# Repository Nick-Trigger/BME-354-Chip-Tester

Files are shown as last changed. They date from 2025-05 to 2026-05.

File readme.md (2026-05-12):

# BME 354 Chip Tester

A custom PCB designed to test analog ICs — specifically the ADC623 and INA126 instrumentation amplifiers — as part of a BME 354 course project.

## Overview

The board provides:

- A sine wave generator signal source
- A regulated voltage supply
- LED indicators for pass/fail output comparison
- Switch-controlled power and signal routing
- Test points for oscilloscope / multimeter probing

## Project Files

| Folder / File | Description |
| --- | --- |
| [KiCad_milling_machine/](KiCad_milling_machine/) | KiCad schematic and PCB layout files (milling-machine spec) |
| [KiCad_milling_machine/Custom Libraries/](KiCad_milling_machine/Custom%20Libraries/) | Custom KiCad symbols and footprints for non-standard parts |
| [Documentation/](Documentation/) | Photos from build and testing stages |
| [Documentation.md](Documentation.md) | Full design log with dated entries and schematic notes |

## Key Schematics

- [ChipTester_354.kicad_sch](KiCad_milling_machine/ChipTester_354.kicad_sch) — top-level schematic
- [AD_INA.kicad_sch](KiCad_milling_machine/AD_INA.kicad_sch) — ADC623 / INA126 test circuit
- [wave_generator.kicad_sch](KiCad_milling_machine/wave_generator.kicad_sch) — sine wave generator sub-circuit
- [pwrsup.kicad_sch](KiCad_milling_machine/pwrsup.kicad_sch) — voltage regulator sub-circuit
- [mcp_if.kicad_sch](KiCad_milling_machine/mcp_if.kicad_sch) — MCP interface sub-circuit

## Design Log

See [Documentation.md](Documentation.md) for a full chronological record of design decisions, breadboard testing, PCB layout, milling, soldering, and troubleshooting.

## Components

Non-standard parts sourced from DigiKey. Custom footprints included in [KiCad_milling_machine/Custom Libraries/](KiCad_milling_machine/Custom%20Libraries/) for:

- `100DP1T2B4M6QE` — DPDT slide switch
- `100SP3T2B4M6RE` — SP3T slide switch
- `7101MD9AQE` — rotary switch
- `BH9VPC` — 9V battery holder
- `PRS12R_4025K_103B1` — potentiometer

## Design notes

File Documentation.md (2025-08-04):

## Circuit Design 
May 19th 2025

* Created beginning of circuit design for for ADC623 INA126 testing circuit 
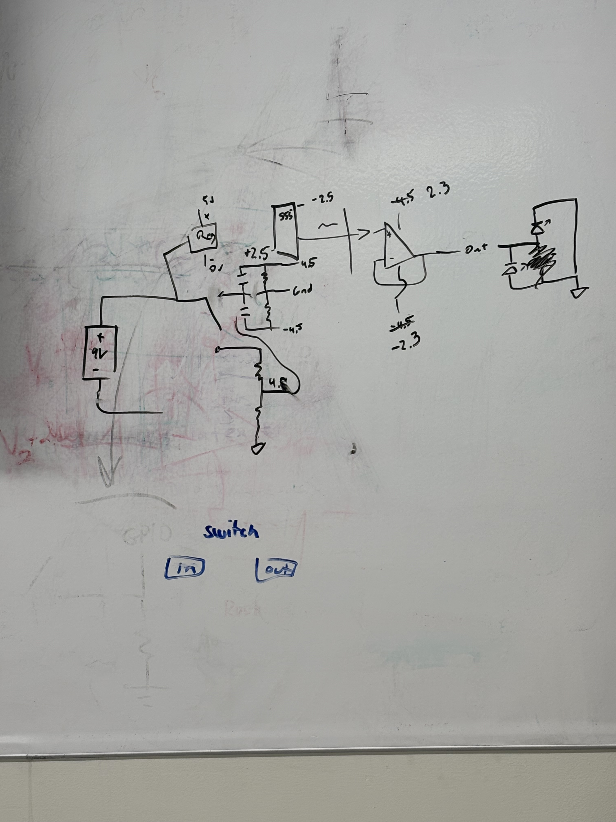
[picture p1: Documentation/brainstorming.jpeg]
Circuit Brainstorming

* Started with Kicad circuit creation

May 20th 2025

* Built and Tested Voltage Regulator Circuit (working)
* Built and Tested Sine Wave Generator Circuit (working)
    * Decided against using 555 timer for sine wave oscillating signal 
    * Both circuits were built on an open breadboard to start with to allow us to troubleshoot easily 
    * Decided on Potentionmeter Min Resistance as 10kOhm 
 
Breadboard Testing Circuits

May 28th 2025

* Ordered components from DigiKey ([List](https://www.digikey.com/en/mylists/list/94XYNUR698))

May 29th 2025 

* Started PCB layout, found footprints for non-standard parts.

June 2nd-3rd 2025

* Reannotated schematic and pcb.
* Finished pcb layout.

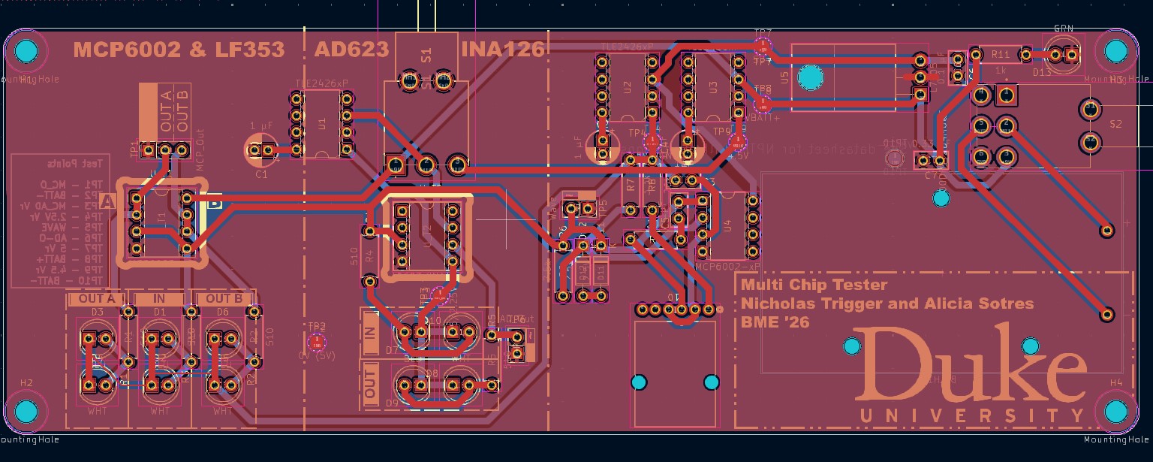
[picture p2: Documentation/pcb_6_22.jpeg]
Finished PCB schematic 6/2/25


June 4th 2025 

* Duplicated board file to modify for milling machine specification.

June 10th 2025 

* Edited PCB schematic for remilling. Fixed clearance issues with tracks. 
* Changed through-hole diameters to allow for rivets to be placed in difficult to solder locations (chip and pin sockets)

June 25th 2025

* Received milled board, tested board for issues before soldering. 
* Soldered main components, need more blue and white LEDS

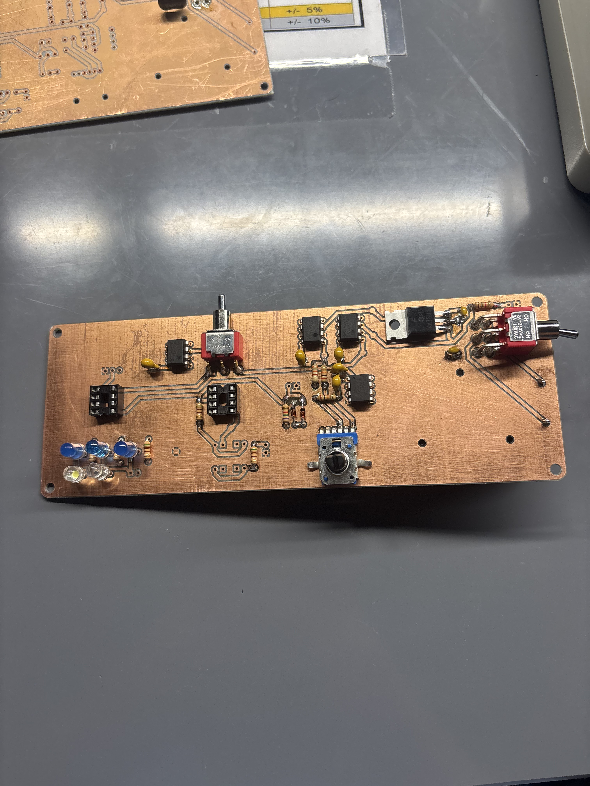
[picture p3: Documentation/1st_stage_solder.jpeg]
Incomplete PCB 6/2/25


July 29th 2025
* Rebuilt circuit on breadboard to troubleshoot known issues identified on first milled PCB
    * Issues included LED ground, necessary chip connections and switch issues. 
    * Removed 2nd switch to simplify circuit logic. 

August 4th 2025 

* Updated schematic to ground LEDs to board GND to allow for simultaneous blinking. 

## PCB & Schematic Notes
* (7/24/2025) The voltage provided by the battery has four different net class names (two before and two after the power switch). This is to distinguish between the nets so that KiCad does not draw a connection between these two signals, bridging across the switch -- making it useless.

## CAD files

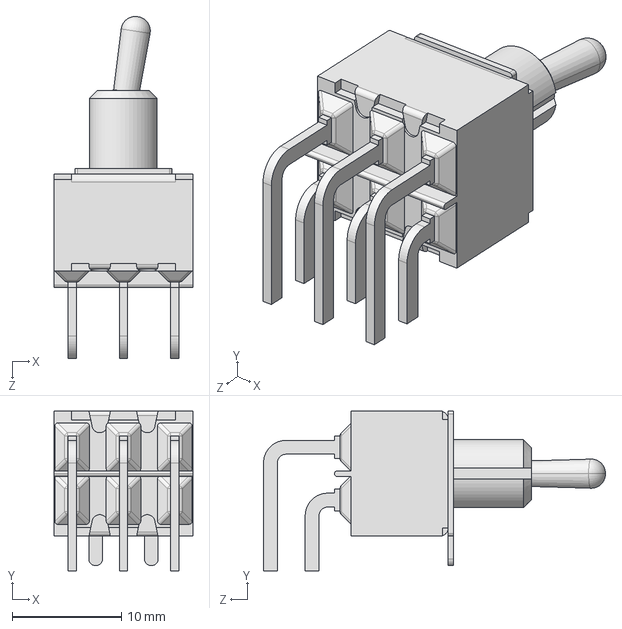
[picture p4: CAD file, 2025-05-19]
KiCad_milling_machine/Custom Libraries/100DP1T2B4M6QE/100DP1T2B4M6QE.step
12.7 x 14.6 x 31.3 mm

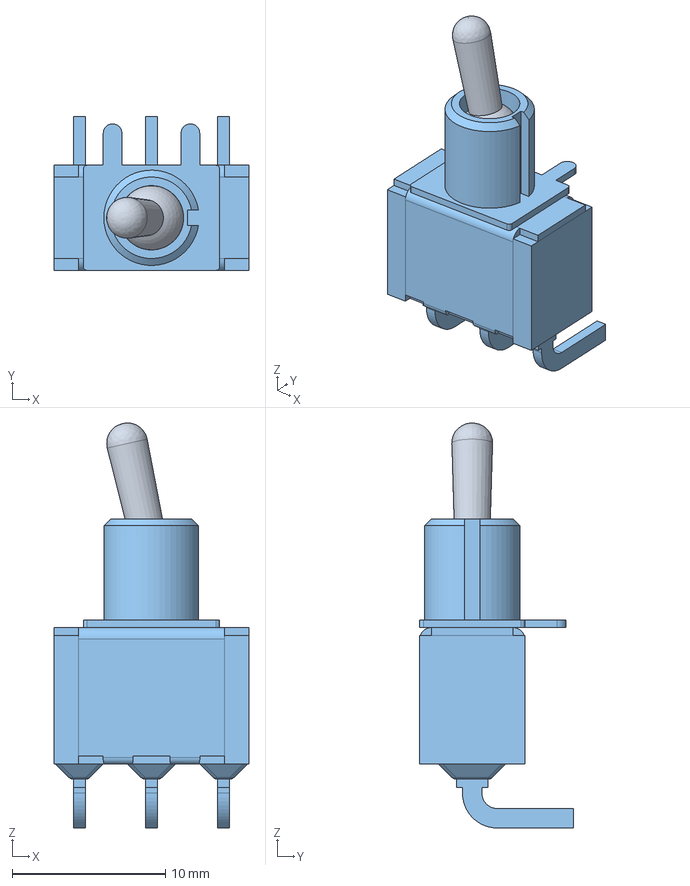
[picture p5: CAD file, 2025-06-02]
KiCad_milling_machine/Custom Libraries/100SP3T2B4M6RE/100SPxT2B4M6xE.stp
12.7 x 10.0 x 26.4 mm

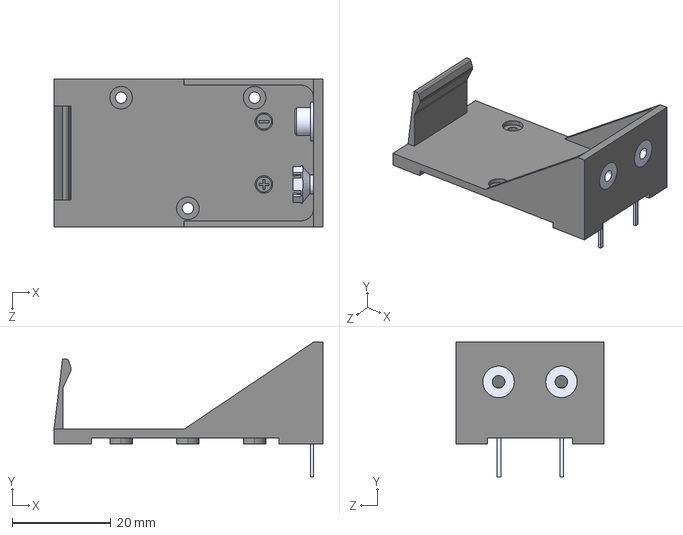
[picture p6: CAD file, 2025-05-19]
KiCad_milling_machine/Custom Libraries/BH9VPC/BH9VPC.step
54.4 x 27.2 x 30.0 mm

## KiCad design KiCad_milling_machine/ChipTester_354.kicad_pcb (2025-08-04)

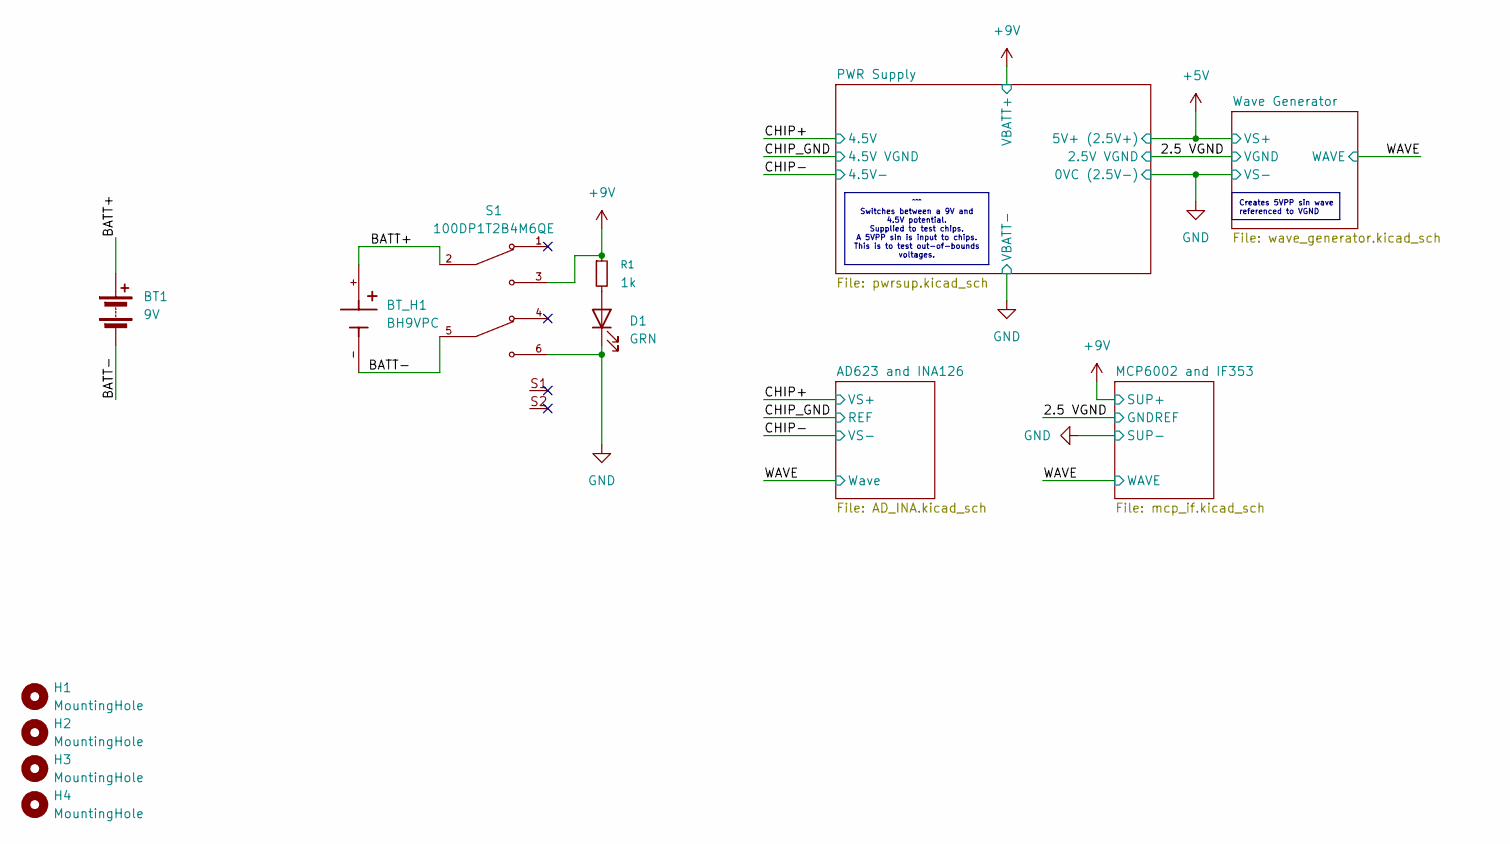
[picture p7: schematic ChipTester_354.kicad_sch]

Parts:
BT1: 9V
BT_H1: BH9VPC; BAT_BH9VPC; PARTREV F
D1: GRN; LED_D5.0mm
H1, H2, H3, H4: MountingHole; MountingHole_3.2mm_M3
R1: 1k; R_Axial_DIN0207_L6.3mm_D2.5mm_P7.62mm_Horizontal
S1: 100DP1T2B4M6QE; SW_100DP1T2B4M6QE; PARTREV G

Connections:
+9V: R1.1, S1.3; also elsewhere on the board
/BATT+: BT1.1 (+), BT_H1.+, S1.2
/BATT-: BT1.2 (-), BT_H1.-, S1.5
GND: D1.1 (K), S1.6; also elsewhere on the board
unnamed: D1.2 (A), R1.2

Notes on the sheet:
Creates 5VPP sin wave referenced to VGND
^^^ Switches between a 9V and 4.5V potential. Supplied to test chips. A 5VPP sin is input to chips. This is to test out-of-bounds voltages.

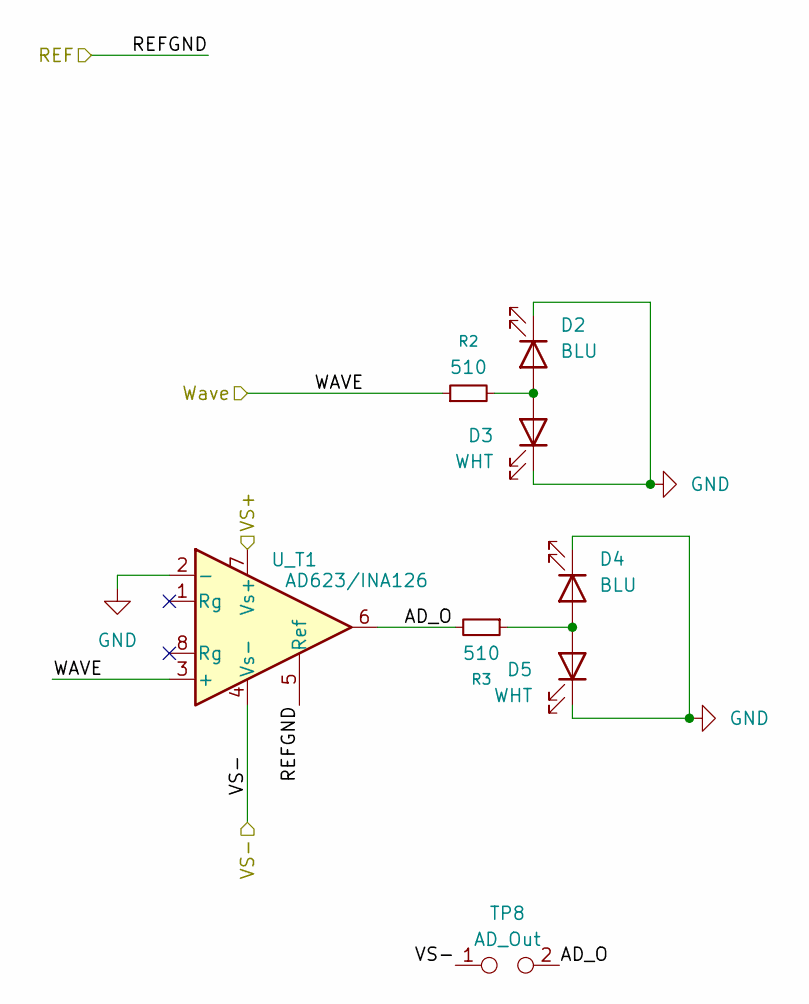
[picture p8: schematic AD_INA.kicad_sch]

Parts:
D2, D4: BLU; LED_D5.0mm
D3, D5: WHT; LED_D5.0mm
R2, R3: 510; R_Axial_DIN0207_L6.3mm_D2.5mm_P7.62mm_Horizontal
TP8: AD_Out; PinSocket_1x02_P2.54mm_Vertical
U_T1: AD623/INA126; DIP-8_W7.62mm_Socket

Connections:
+9V: U_T1.7 (Vs+); also elsewhere on the board
/AD623 and INA126/AD_O: R3.2, TP8.2, U_T1.6
/CHIP_GND: U_T1.5 (Ref); also elsewhere on the board
/WAVE: R2.1, U_T1.3 (+); also elsewhere on the board
GND: D2.1 (K), D3.1 (K), D4.1 (K), D5.1 (K), TP8.1, U_T1.2 (-), U_T1.4 (Vs-); also elsewhere on the board
unnamed: D2.2 (A), D3.2 (A), R2.2
unnamed: D4.2 (A), D5.2 (A), R3.1

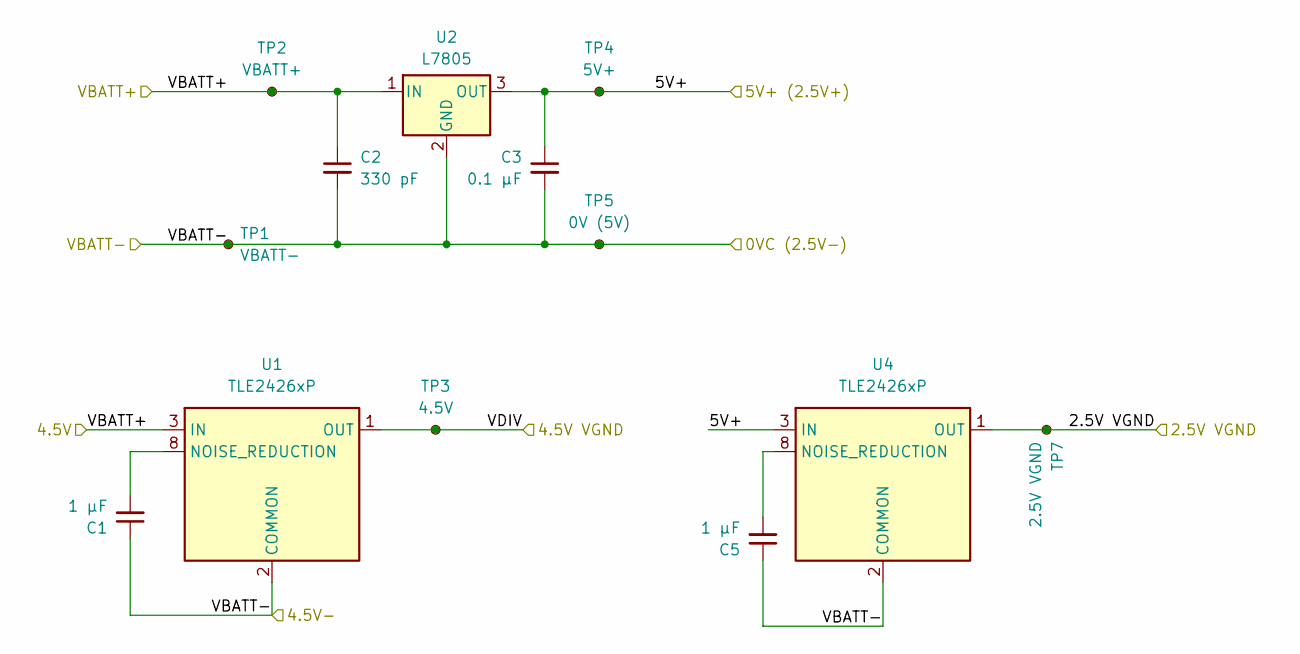
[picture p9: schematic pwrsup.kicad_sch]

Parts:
C1, C5: 1 µF; CP_Radial_D5.0mm_P2.00mm
C2: 330 pF; C_Disc_D5.0mm_W2.5mm_P2.50mm
C3: 0.1 µF; C_Disc_D5.0mm_W2.5mm_P2.50mm
TP1: VBATT-; TestPoint_Pad_D2.0mm
TP2: VBATT+; TestPoint_Pad_D2.0mm
TP3: 4.5V; TestPoint_Pad_D2.0mm
TP4: 5V+; TestPoint_Pad_D2.0mm
TP5: 0V (5V); TestPoint_Pad_D2.0mm
TP7: 2.5V VGND; TestPoint_Pad_D2.0mm
U1, U4: TLE2426xP; DIP-8_W7.62mm
U2: L7805; TO-220-3_Horizontal_TabDown

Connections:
+5V: C3.1, TP4.1, U2.3 (OUT), U4.3 (IN); also elsewhere on the board
+9V: C2.1, TP2.1, U1.3 (IN), U2.1 (IN); also elsewhere on the board
/2.5 VGND: TP7.1, U4.1 (OUT); also elsewhere on the board
/CHIP_GND: TP3.1, U1.1 (OUT); also elsewhere on the board
GND: C1.1, C2.2, C3.2, C5.1, TP1.1, TP5.1, U1.2 (COMMON), U2.2 (GND), U4.2 (COMMON); also elsewhere on the board
unnamed: C1.2, U1.8 (NOISE_REDUCTION)
unnamed: C5.2, U4.8 (NOISE_REDUCTION)

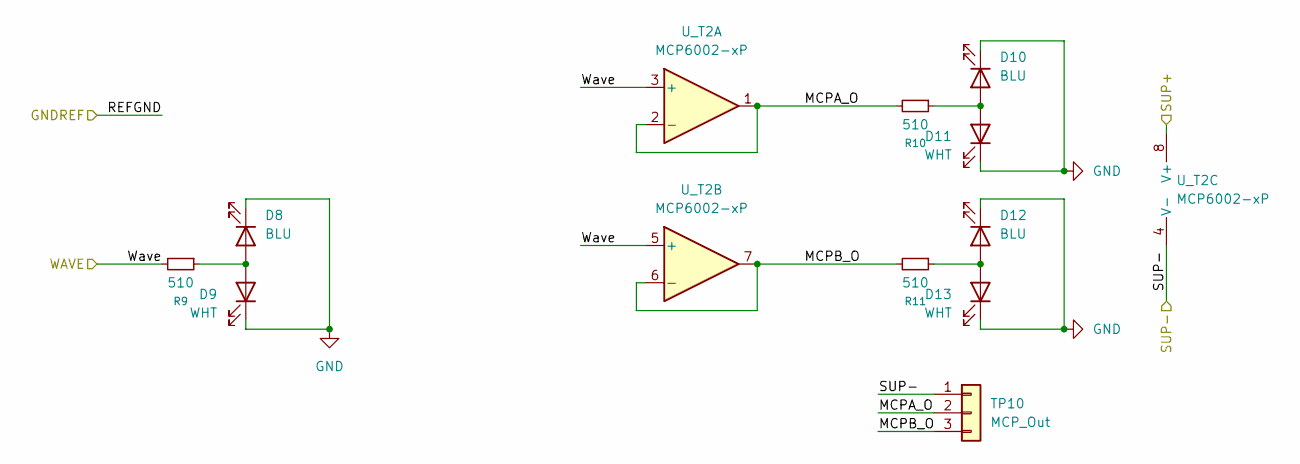
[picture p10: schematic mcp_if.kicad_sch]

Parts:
D8, D10, D12: BLU; LED_D5.0mm
D9, D11, D13: WHT; LED_D5.0mm
R9, R10, R11: 510; R_Axial_DIN0207_L6.3mm_D2.5mm_P7.62mm_Horizontal
TP10: MCP_Out; PinSocket_1x03_P2.54mm_Vertical
U_T2: MCP6002-xP; DIP-8_W7.62mm_Socket

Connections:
+9V: U_T2.8 (V+); also elsewhere on the board
/MCP6002 and IF353/MCPA_O: R10.2, TP10.2, U_T2.1, U_T2.2 (-)
/MCP6002 and IF353/MCPB_O: R11.2, TP10.3, U_T2.6 (-), U_T2.7
/WAVE: R9.2, U_T2.3 (+), U_T2.5 (+); also elsewhere on the board
GND: D8.1 (K), D9.1 (K), D10.1 (K), D11.1 (K), D12.1 (K), D13.1 (K), TP10.1, U_T2.4 (V-); also elsewhere on the board
unnamed: D8.2 (A), D9.2 (A), R9.1
unnamed: D10.2 (A), D11.2 (A), R10.1
unnamed: D12.2 (A), D13.2 (A), R11.1

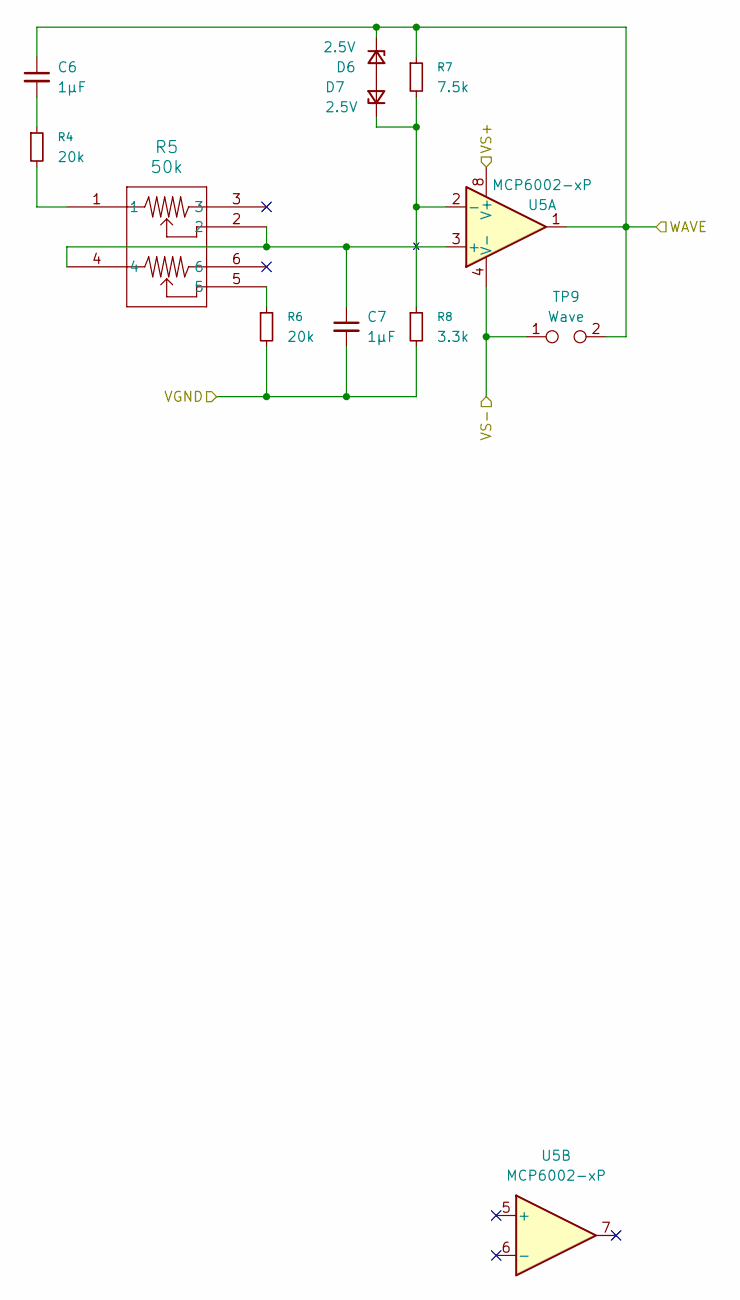
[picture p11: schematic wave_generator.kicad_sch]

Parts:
C6, C7: 1µF; C_Disc_D5.0mm_W2.5mm_P2.50mm
D6, D7: 2.5V; D_DO-35_SOD27_P7.62mm_Horizontal
R4, R6: 20k; R_Axial_DIN0207_L6.3mm_D2.5mm_P7.62mm_Horizontal
R5: 50k; PRS12R-4_BRN
R7: 7.5k; R_Axial_DIN0207_L6.3mm_D2.5mm_P7.62mm_Horizontal
R8: 3.3k; R_Axial_DIN0207_L6.3mm_D2.5mm_P7.62mm_Horizontal
TP9: Wave; PinSocket_1x02_P2.54mm_Vertical
U5: MCP6002-xP; DIP-8_W7.62mm

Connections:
+5V: U5.8 (V+); also elsewhere on the board
/2.5 VGND: C7.2, R6.2, R8.2; also elsewhere on the board
/WAVE: C6.1, D6.1 (K), R7.1, TP9.2, U5.1; also elsewhere on the board
GND: TP9.1, U5.4 (V-); also elsewhere on the board
unnamed: C6.2, R4.1
unnamed: D6.2 (A), D7.2 (A)
unnamed: D7.1 (K), R7.2, R8.1, U5.2 (-)
unnamed: R4.2, R5.1
unnamed: R5.5, R6.1
unnamed: C7.1, R5.2, R5.4, U5.3 (+)

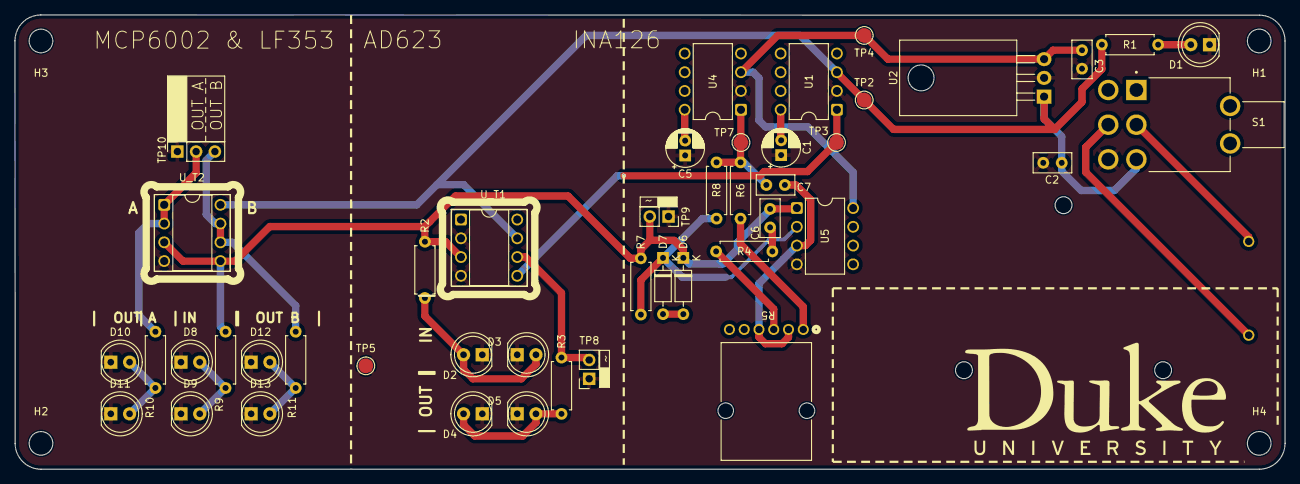
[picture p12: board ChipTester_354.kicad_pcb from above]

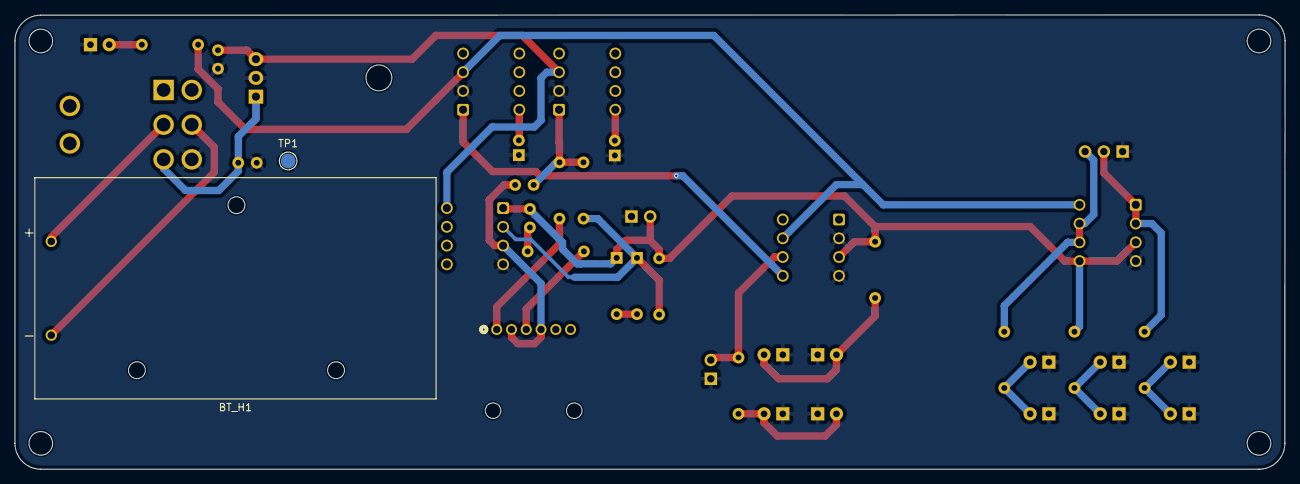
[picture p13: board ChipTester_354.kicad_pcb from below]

Board: 2 copper layers, 172.0 x 61.5 mm, 51 parts (2 on the bottom side), 25 nets.

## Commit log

2025-05-19 Added KiCad Docs and started working
    [100DP1T2B4M6QE.step, BH9VPC.step, ChipTester_354.kicad_pcb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]
2025-05-20 Finish power supply, make waveform generator.
    [AD_INA.kicad_sch, ChipTester_354.kicad_sch, pwrsup.kicad_sch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]
2025-05-21 changed resistance on schematic for minimum reisstance of 20kOhm
    [wave_generator.kicad_sch]
2025-05-28 changed resistor values after testing
    [wave_generator.kicad_sch]
2025-05-28 Change to TI rail splitter.
    [pwrsup.kicad_sch, wave_generator.kicad_sch]
2025-05-28 Swapped mcp6002 rail splitter for TI TLE2426xP
    [pwrsup.kicad_sch, wave_generator.kicad_sch]
2025-05-28 started edited pcb layout
    [ChipTester_354.kicad_pcb, ChipTester_354.kicad_sch, pwrsup.kicad_sch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]
2025-05-28 ADD AC623 and INA126 Test Circuitry
    [AD_INA.kicad_sch, ChipTester_354.kicad_sch]
2025-05-28 added footprints to schematic
    [AD_INA.kicad_sch, ChipTester_354.kicad_pcb, pwrsup.kicad_sch]
2025-05-28 Update battery switch to dpdt.
    [ChipTester_354.kicad_sch, wave_generator.kicad_sch]
2025-05-28 Add power led
    [AD_INA.kicad_sch, ChipTester_354.kicad_sch, pwrsup.kicad_sch]
2025-05-29 updated footprint to be all THT, battery holder still not there
    [AD_INA.kicad_sch, ChipTester_354.kicad_pcb, ChipTester_354.kicad_sch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]
2025-05-29 Some TP -> Headers, added footprints, fixed battery footprint, started layout of board.
    [AD_INA.kicad_sch, ChipTester_354.kicad_pcb, ChipTester_354.kicad_sch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]
2025-05-30 Made the board :D
    [AD_INA.kicad_sch, ChipTester_354.kicad_pcb, ChipTester_354.kicad_sch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]
2025-06-02 Added annotations to pcb
    [100SPxT2B4M6xE.stp, ChipTester_354.kicad_pcb]
2025-06-04 added second kicad proejct folder
    [100DP1T2B4M6QE.step, 100SPxT2B4M6xE.stp, AD_INA.kicad_sch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]
2025-06-04 adding to pull
    [ChipTester_354.kicad_sch]
2025-06-04 Added milling machine files / updated schematic+pcb annotations / updated footprints
    [AD_INA.kicad_sch, ChipTester_354.kicad_pcb, ChipTester_354.kicad_sch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]
2025-06-08 Add PCB Image
2025-06-10 re-edited for 2nd milling, fixing clearances and problem areas
    [ChipTester_354.kicad_pcb, pwrsup.kicad_sch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]
2025-07-25 Removed Switch
    [AD_INA.kicad_sch, ChipTester_354.kicad_pcb, ChipTester_354.kicad_sch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]
2025-07-25 Updated Documentation with Info on Schematic Labelling
2025-07-25 Ground inverting input of AD/INA circuit
    [AD_INA.kicad_sch, ChipTester_354.kicad_pcb]
2025-08-04 grounded LEDs to allow for sufficient voltage blinking difference
    [AD_INA.kicad_sch, ChipTester_354.kicad_pcb, mcp_if.kicad_sch]
2025-08-04 updated documentation and removed old milling files
    [ChipTester_354-B_Cu.gbr, ChipTester_354-Edge_Cuts.gbr, ChipTester_354-F_Cu.gbr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]
2025-08-11 deleted old version, milling machine folder is reflective of most recent chip design
    [100DP1T2B4M6QE.step, 100SPxT2B4M6xE.stp, AD_INA.kicad_sch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]
